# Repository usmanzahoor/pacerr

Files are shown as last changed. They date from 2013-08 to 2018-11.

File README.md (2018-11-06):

#pacerr 

#####Partially Arduino Controled Rover Robot

***PACERR is an arduino based robot that takes commands from a Bluetooth source and translates them into other messages (motor movements).***

#### Short Description

Pacerr can take commands from any Bluetooth terminal as well as the Blackberry 10 app included in the downloads. The app is just a polished version of the simple bluetoothchat example released by Blackberry themselves. I have also included the code for two possible Android apps you can use. They are in the trunk folder of the source. I have not compiled them and you need to do that on your own. 

I have included the necessary bare basic code for the rover. I will also include several different codes you can apply. You can, by all means, use the codes and build upon them or just use them as is to make your own Pacerr. I will also include files such as .pcb and other schematic for the project as I want to make it as easy as possible to have fun with arduino and BT without going through many hassles. All I ask for is a bit of credit :)

#### WIKI

Make **SURE** to read the wiki pages. (Left menu)

#### Site

Checkout the website for some more useful info! 

####Pictures
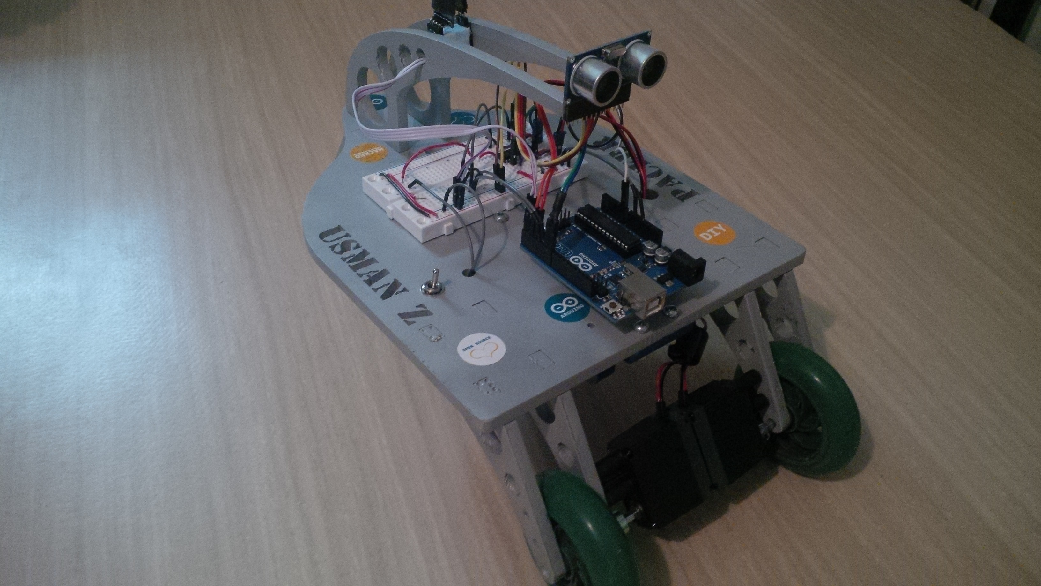
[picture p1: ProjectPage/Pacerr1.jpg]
PACERR Final Picture 2|alt=PACERR being built


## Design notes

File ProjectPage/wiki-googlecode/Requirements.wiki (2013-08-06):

#summary Step 1. Required things for the project.
#labels Requirements,Phase-Requirements

== What do I need? ==

Alright, so let's get started!

What will you need and need to do before the project? Well here is what I did and recommend. 

===Model===
First, you should make some sort of model for your rover. It can be any thing you like and look however you want. I used Autodesk Inventor for my modeling. (If you are a student, get the software for FREE!)  Check out the rendered model I have made. (I will possibly upload my models to GrabCAD, so check that out too)

The only thing to remember when making your models, is to make sure everything goes together nicely and you have plenty of room for the hardware you will need and want to use. 

I will be cutting out my model from aluminum using a waterjet, so when you are making your model, make sure you have someway of cutting it out/ making it. 

===Physical Requirements===
By 'Physical' I mean actual stuff you'll need. 

Here is a basic list:

-An Arduino (I'm using Uno)+ the required software: http://www.arduino.cc/ 

-Fitzrig software for schematics and ordering/making a PCB: http://fritzing.org/

-A Breadboard for prototyping 

-Cables, wires, wire strippers, jumper cables ... 

-Motors (at least 2) (I'm using these ones: http://www.vexrobotics.com/276-2181.html)

-A Bluetooth dongle for arduino 

http://thumbs3.ebaystatic.com/m/mDeCohFDeVs02PIr9CCkcQw/96.jpg

-An Android device or any other with Bluetooth and Bluetooth Terminal capabilities

That's about it for now. And also of course a computer.

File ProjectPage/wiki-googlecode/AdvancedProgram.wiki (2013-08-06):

#summary Step 4.Advanced PACERR program with servo, ultrasonic sensor, photocells and different mode incorporation.
#labels Featured,Phase-Implementation,Phase-Deploy

= Intro =

So now that you've read up on the basic program for the robot (if you haven't make sure you read that before this), you'll be wanting to improve the performance of the robot. 

Because the code is long and complicated, I'll divide it up into various sections for the various parts of the code. 

_Note in Final2.ino, there are some lines of code with `//` in front of them. Theses are currently *NOT* active in the code and you might want to activate them by removing the two slashes. Don't worry if you don't understand what this means yet. After going through these wikis you should have a better idea.

==Review==

This stuff is basically just a review of the basic program. 
So we know that at the top, there are the variable declarations for arduino to know what stands for what and where to store data.

{{{
char incomingByte;
int leftDrivePin = 6;      // left motor
int rightDrivePin = 5;      // right motor
int leftDirectionPin = 7;   // direction - left motor
int rightDirectionPin = 4;  // direction - right motor
}}}

We've already discussed what these lines do in the last page.

{{{
void setup() 
{
  Serial.begin(9600);
  pinMode(leftDrivePin, OUTPUT);
  pinMode(rightDrivePin, OUTPUT);
  pinMode(leftDirectionPin, OUTPUT);
  pinMode(rightDirectionPin, OUTPUT);
  Serial.println("connection successful. enter command, R, B, S, L, or F");
}
}}}

This is the set-up function and it tells arduino if to read signals from a specific pin or send signals or power out. 

{{{
void loop() 
{
  if (Serial.available() > 0) {
    incomingByte = Serial.read();
    if (incomingByte == 'F') {
        digitalWrite(leftDirectionPin,HIGH);
        digitalWrite(leftDrivePin, LOW);
        digitalWrite(rightDirectionPin,HIGH);
        digitalWrite(rightDrivePin, LOW);
        Serial.println("Forwards");
    }
  ...
   }
}
}}}

This is the loop function. This means that the processes in here will continue until power is removed from the arduino.

If you don't understand these parts, you should probably look at the tutorial titled: StepTwoProgramming

==Final2==
===Declarations===

Alright, so now have a look at the sketch Final2.ino. 

There are new lines at the top declaring more things. 

{{{
#include <Servo.h>
}}}

We will be using the servo library that comes with arduino. This line just lets the ide know we will be doing that so we can manipulate the servo easier.

{{{
const int trigPin = 2; // trigPin 
const int echoPin = 3; // echoPin 
}}}

These lines are dependent on the type of ultrasonic sensor you use. I am using the HC-SR04 and on it there are four pins. Vcc (power), Trig, Echo and Gnd.

The trig and echo pins do most of the work. The are connected mainly to the two drums. One of them sends sound signals and the other ones receives (trig and echo). 

Here you declare that the digital pin 2 on the arduino will be connected to the trig pin on the ultrasonic sensor and the same for the echo pin.

{{{
const int lsPin = A1;
const int ambient = 500;    //natural
const int threshold = 600;  //steering 
int lightLeft = 0;
int lightRight = 0; 
}}}

The line `const int lsPin = A1;` is letting the arduino know that Analog pin labeled A! will be used to check if the photocells are active to switch to steering with a flash light mode. 

The lines `const int ambient = 500;` and `const int threshold = 600;` are letting the arduino know that the ambient level of light for the photo cells is 500 and the threshold or the least amount of light needed to steer in 600.

The two `int` statements are just to store the amount of light going to the left and right photocells.

{{{
char incomingByte;          // steering mode commands
const int btPin = A0;
int leftDrivePin = 4;       // left motor
int rightDrivePin = 6;      // right motor
int leftDirectionPin = 5;   // direction - left motor
int rightDirectionPin = 7;  // direction - right motor
int enable1 = 9;            // left motor
int enable2 = 10;           // right motor
}}}

These lines have been discussed in the previous wiki page.

{{{
const int minSafeDist = 35; 
int centerDist, leftDist, rightDist, backDist; // Define variables center, left, right and back distance

Servo myservo; //declare servo
}}}

The `const int minSafeDist = 35;` declares that if there is something 35 cm in front of our robot it should do what we tell it to do (in our case preform a scan for available routes).

The ints are again just ways to store data and the `Servo myservo;` is letting the ide know that from now on we will call our servo `myservo`.

===void setup ()===

{{{
void setup() 
{
  Serial.begin(9600);
  // Set all the pins and the servo
  pinMode(btPin, INPUT);
  pinMode(leftDrivePin, OUTPUT);
  pinMode(rightDrivePin, OUTPUT);
  pinMode(leftDirectionPin, OUTPUT);
  pinMode(rightDirectionPin, OUTPUT);
  //pinMode(lights, OUTPUT);
  pinMode(trigPin, OUTPUT);
  pinMode(echoPin, INPUT);
  digitalWrite(enable1, HIGH);
  digitalWrite(enable2, HIGH);
  myservo.attach(11);
  myservo.write(95);
  // Initial message
  Serial.println("connection successful. enter '?' for list of commands.");
}
}}}

This is pretty self explanatory but if you do not understand it have a look at the previous wiki page (the one you should have already read before this one).

The new lines however I will go over.

{{{
  myservo.attach(11);
  myservo.write(90);
}}}

These lines refer back to our servo called `myservo`. So the .attach command is telling the arduino that we will attach out servo's inout pin to the arduino digital pin 11.

The .write line is telling which angle to set the servo up to start. In this case at 90 degrees so it is looking forwards. And then it can turn 0 degrees to look right and 180 degrees to look left.

===void loop () and the autonomous function===

This is what does the magic for us. 

First, the arduino checks if either the buletooth pin or the photo cells are powered on. If they are, it either goes into manual mode (bluetooth) or lightsteer mode (photocells)/

{{{
//check if we are using the bluetooth module, if so listen for commands only
  if( digitalRead(btPin) == HIGH ) { 
    manual();
    return;
  }
  //check if the photosensors are on, if so follow light only
  if( digitalRead(lsPin) == HIGH && digitalRead(btPin) == LOW ) { 
    lightsteer();
    return;
  }
}}}

That is why above, we connected the bluetooth module to the A0 pin and the photocells to the A1 pin. 

The arduino checks if either of these things is receiving power.
If the bluetooth module is receiving power `if( digitalRead(btPin) == HIGH ) {` and if it is then
 
{{{
    manual();
    return;
}}} 

perform the manual function. Which is basically the void loop of the basic code. 

If the photocells get power AND the bluetooth doesn't get power 'if( digitalRead(lsPin) == HIGH && digitalRead(btPin) == LOW ) {` then:

{{{
    lightsteer();
    return;
}}}

preform the lightsteer function (I'll describe it below).

If none of these things happens, then preform the autonomous functions:

{{{
centerDist = getDistance();  
    
  if(centerDist >= minSafeDist) /* If the inches in front of an object is greater than or equal to the minimum safe distance react*/
  {
    forward(); // All wheels forward for seconds
  }
  else // If not:
  {
    brake(); // Stop all motors
    backward();
    delay(600);
    lookAround(); // Check your surroundings for best route
    if(rightDist > leftDist) // If the right distance is greater than the left distance , turn right
    {
      right();
    }
    else if (leftDist > rightDist) // If the left distance is greater than the right distance , turn left
    {
      left();
    }
    else if ( leftDist&&rightDist < minSafeDist ) // If the left and right distances are smaller than the min safe distance go back
    {
      backward();
      delay(1000);
    }  
  }
}}}

So what's going on here? Well, first of all `centerDist = getDistance();` is saying that to find the distance in front of the robot, you must preform the function called 'getDistance'.

Then, if the center distance is greater than the minimum safe distance, go forward until something comes in front of the robot. 

If there is something in front, then stop (`brake();`) go back a bit (`backward(); delay(600);`) then `lookAround();` for safe distances. 

Once the robot has looked around, this is what happens:

  If the right distance is greater than the left, then turn right for one second and continue forward.

  If the left distance is greater than the right, then turn left for one second and continue forward.  

  If the left and right distances are smaller than the min safe distance go back.

This pretty much covers the 'autonomous' function and how the robot moves around unassisted. Later on, you might want to add a temp and humidity sensor or other data collection sensors and as the robot is moving around, it could send the data back over to serial.

What you'll have to do then, is tell the robot, that when bluetooth is on, still preform auto mode and send serial outs and add a button maybe to switch modes. But right now, you don't have to worry about that.

===Manual method and functions===

The manual methods of this robot are really just the same as the basic program. Have a look and you'll see that the only difference is that there is the line:

{{{
void manual()
{
...
}
}}}

above the code. This is letting the ide (btw, ide stands for integrated development environment, so the program you are using on your computer) know that the lines curly braces are not `void loop ()` like in the basic code but are `void manual ()` and we can call them when ever (well almost when ever) by using `manual();`

An example of this mentioned earlier is in lines 57-60:

{{{
if( digitalRead(btPin) == HIGH ) {
manual();
return;
}
}}}

You'll recognize these from above. So basically what is happening is that we tell the arduino that if btPin, or pin A0, is NOT detecting power, then go ahead and preform the `manual();` function. 

And then we go ahead and let it know what the `manual();` function is exactly by creating a 

{{{
void manual()
{
...
}
}}}

===The light steering function===

{{{
void lightsteer()
{
  // Read light sensors connected to
  // analog pins A2 and A3
    lightLeft = analogRead(A2);
    lightRight = analogRead(A3);
     // Stop robot if below ambient
     if (lightRight < ambient || lightLeft < ambient) {
     brake();
     } else {
     forward();
      // Steer to right if right CdS below threshold
      if (lightRight < threshold) {
      left();
  delay (250);
}
      // Steer to left if left CdS below threshold
      forward();
      if (lightLeft < threshold) {
      right();
  delay (250);
  }
 }
}
}}}

So this function is obviously called by `lightsteer();` (in lines 62 - 65).

Here is what happens: 

The two sensors that we declared near the top of the sketch `lightLeft` and `lightRight` are assigned analog pins `A2` and `A3`.

Now:

  {{{
    if (lightRight < ambient || lightLeft < ambient) {
       brake();
  }}}

  if there is less light than the amount we declared near the top facing both of the photocells, then perform the `brake();` function. or if there is light shining on both both the cells, then perform `forward():`

  and

  {{{
    if (lightRight < threshold) {
        left();
    delay (250);
  }
  }}}

  if there is more light on the right cell, turn left and the opposite for the other cell.

Pretty easy and simple.

===Motor methods===

These functions just are the movement functions, like brake = all motors off and forward = all motors on and left = right motor forward and left motor either off or `LOW`, backwards).

Again, by now you should be able to decipher these as well pretty easily.

===Servo methods===

Something new, yay! But unfortunately (or maybe not for you) pretty easy to understand).

{{{
/* Servo methods */
void lookRight()
{
myservo.write(180);
delay(320);
}

void lookLeft()
{
myservo.write(0);
delay(320);
}

void lookAhead()
{
myservo.write(95);
delay(320);
}

void lookAround()
{
lookRight();
rightDist = getDistance();

lookLeft();
leftDist = getDistance();

lookAhead();
centerDist = getDistance();
}
/* End of servo methods */
}}}

Here we manipulate the `myservo.write( -angle- );` command from the library. So if you look at your servo, 90 degrees is looking forwards and so 180 is looking to the left and 0 is looking to the right.

http://www.seattlerobotics.org/guide/images/pulse_code.jpg

In every function, we use the .write command to move the servo at a specific angle then in the `void lookAround()` we store the measurement data.

So in `void lookAround()` we `lookRight();` then we `getDistance();` and then we store it in the variable we declared at the top of the code as `rightDist` and so on for the other angles.

===The ultrasonic sensor explained===

{{{
int getDistance()
{
long duration;
digitalWrite(trigPin, LOW);
delayMicroseconds(2);
digitalWrite(trigPin, HIGH);
delayMicroseconds(10);
digitalWrite(trigPin, LOW);
duration = pulseIn(echoPin, HIGH);
return duration / 2 / (29+(1/10));
}
}}}

The ultrasonic sensor, in most cases has two 'drums' and sometimes even just one that does both jobs. I'll explain the HC-SR04.

On the U' sensor, one 'drum' is trig and the other is 'echo'. Look at the following diagram:

http://www.robotc.net/w/images/thumb/c/c8/Ultrasonic_Sensor_Concept_Diagram.png/400px-Ultrasonic_Sensor_Concept_Diagram.png

In the code block, we first do `long duration;` this is just saying we are making a new variable called 'duration' to store data.

What we do in the next few lines is make trigPin send out ultrasonic waves and as the bounce back, make the pulse pin determine how long it took in ms.

Then we say ok, the 'duration' is the time it took. 

Now comes the bit that turns the duration into the distance.

{{{
return duration / 2 / (29+(1/10));
}}}

What we do is take the 'duration' and divide it by 2 then by 29.1 and this gives us the distance to the object which the u' sensor is facing. 

==Final notes==

So hopefully now you understand the code that makes the robot do what it does. Feel free to change the code to your liking and use it but make sure you follow the license terms.

If you have any questions about the code, feel free to email me at:
_*uzahoor10@gmail.com*_

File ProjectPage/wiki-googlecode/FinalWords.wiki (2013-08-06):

#summary Done!Final notes and info for hook up.
#labels Phase-Support

I hope you enjoyed and learned lots from the wiki pages.

Hopefully now you understand the code that makes the robot do what it does. 

Feel free to change the code to your liking and use it but make sure you follow the license terms.

If you have any questions about the code, feel free to email me at:
_*uzahoor10@gmail.com*_

I will post pictures of my own robot. All the code I used is available (for the arduino as well as the android and blackberry apps).

I will also post pictures of the hook-up so you get a good idea of how to set the robot up. 

You will find this hook-up diagram in the downloads tab.

==Hook-up==

For the hook-up, the IC (chip connected to the motor pins), is what controls the motors.

As I mentioned before, *DO NOT* simple attach the motors to the arduino you *MUST* use an h-bridge:

http://fritzing.org/media/fritzing-repo/projects/a/arduino-l293d/images/l293d_pl.jpg

http://3.bp.blogspot.com/-ou_idTKaKFU/UQkOzgdzbnI/AAAAAAAAArM/_jYpJ7KwSfQ/s1600/WORKING.jpg

==L293D==

Follow the above diagram *BUT* for pins 1 & 9 attach them to the arduino pins 9 & 10.

This is so you can control the motor speeds if you want later on.

Thanks for reading! :D

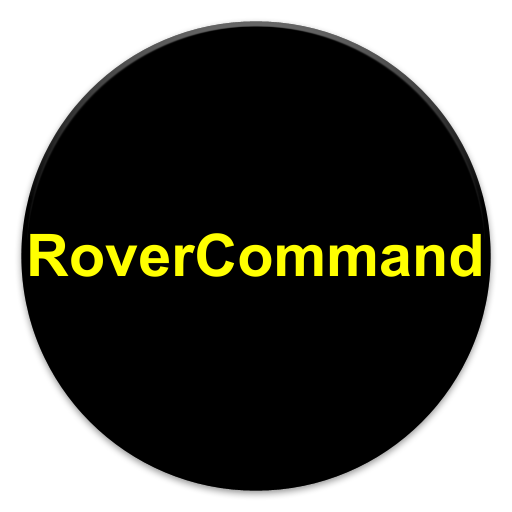
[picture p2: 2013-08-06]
Android/RoverCommandv2/ic_launcher-web.png

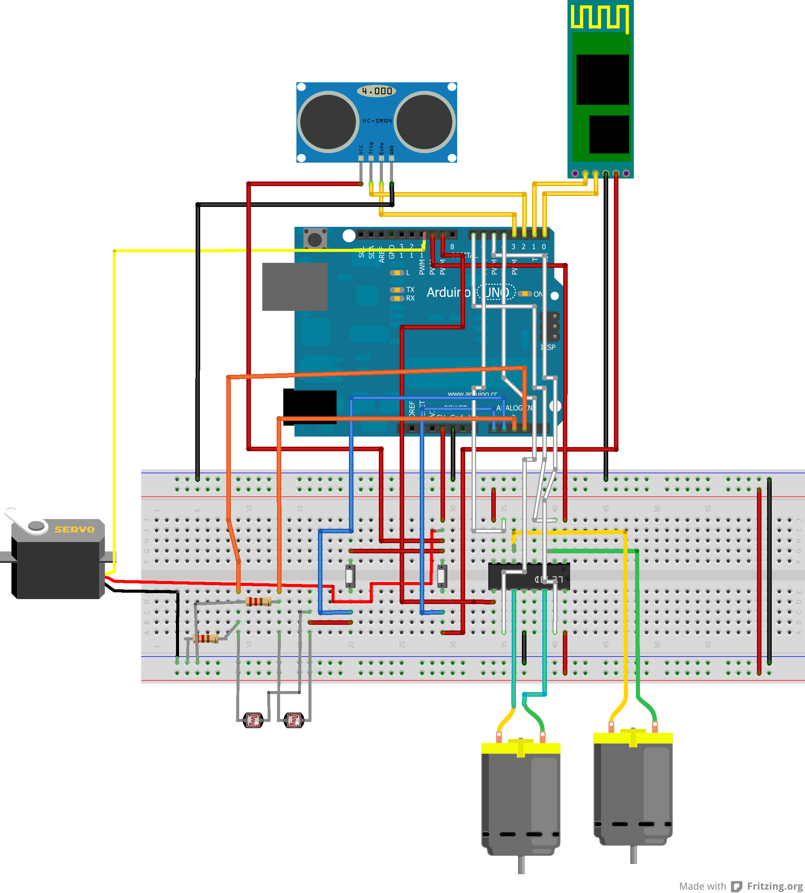
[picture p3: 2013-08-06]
HookUp/Hook-up.png

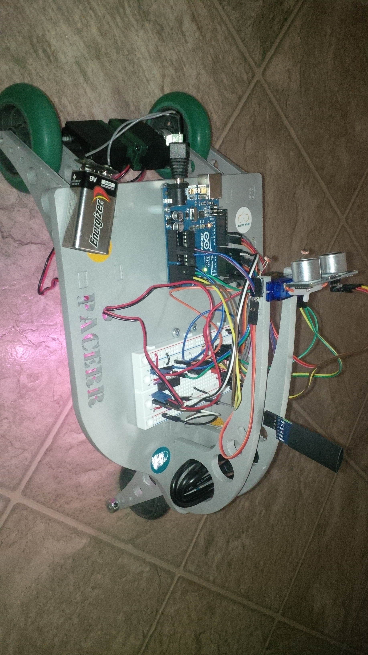
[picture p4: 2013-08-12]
ProjectPage/Pacerr2.jpg

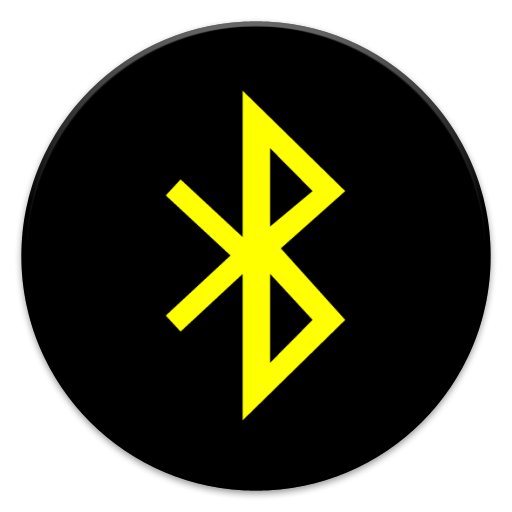
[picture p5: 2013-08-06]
Android/RoverCommand/ic_launcher-web.png

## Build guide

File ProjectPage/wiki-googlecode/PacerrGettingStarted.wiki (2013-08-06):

#summary Intro to project. MUST READ!
#labels Featured,Phase-Requirements

= Introduction =

Hello,
Welcome to PACERR! As mentioned before, this project is a part of a school project called ENEX. 

To learn a bit about the project, look at the project homepage: http://code.google.com/p/pacerr. 

So first of all, let me tell you that this ‘robot’ will work with two motors or four motors. With four motors, you would just run the command pins at the same place as the other motor on the adjacent side.

O,,1,,    O,,2,,

O,,1,,   O,,2,,

As you can see above, the command pins for both O1 motors will be the same or on a breadboard on the same pin side and the ones for O2 will be the same.

For this project, I will only be providing code assuming that you are only using two motors or the situation mentioned above. 

Also, the specific Android app will also need to be tweaked for your custom needs. For example, you will need to use the code for the .apk and modify the MAC address lines in the ‘src/com/example/rovercommand/mainactivity’ and add the MAC address of your OWN Bluetooth module. 

I have also made a blackberry 10 app: http://appworld.blackberry.com/webstore/content/26018872/?countrycode=CA

As you can tell the android app code compliments the arduino code. For example, in the arduino code, I have defined the command for ‘forwards’ as simple ‘F’. This means that only the Bluetooth command ‘F’ will make the motors turn in a forward direction. Now in the app’s java file (mentioned above), you will see that the button ‘Forwards’ sends the command ‘F’ which results in a forward motion. If you want to change the arduino code, you will have to also modify the app. For my final presentation, I will greatly modify the GUI of the app and also add a text reader so the user can modify the MAC address without having to recompile the app.

For the blackberry app, you have the option to search for the bluetooth device and the deploy commands via terminal (SPP).

You can use a simple Bluetooth terminal and send the commands: F, B, S, L, or R and the motors should respond. But you will need to connect the Bluetooth module to the specific Bluetooth terminal you will be using. 

So, let's get started. Check out the next wiki page!

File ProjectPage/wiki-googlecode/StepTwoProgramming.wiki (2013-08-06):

#summary Step 3. Now on to the programming.
#labels Featured,Phase-Implementation

=Programming with the simple code=

Alright, so now you have your model or sketch ready. Now what?

Well, let's get on to the programming aspect. I have provided, in the downloads and source tabs, different ways to program arduino.

The ENEXRoverX.ino sketches (btw arduino code files are called sketches) are just simple ways to control the robot with serial (or bluetooth).

First, let me explain how everything works.

===ENEXRoverX.ino code files and how they work + Arduino functionality===

The first lines of code above the void loop () function are to let arduino know which pins do what. 

{{{
char incomingByte;
int leftDrivePin = 6;      // left motor
int rightDrivePin = 5;      // right motor
int leftDirectionPin = 7;   // direction - left motor
int rightDirectionPin = 4;  // direction - right motor
}}}

The 'char incomingByte line is declaring the fact that in the loop function where we look for the serial commands, the commands (ie "F" or "B") will be stored in a variable called "incomingByte".

(the "//" lines are just comments )

Now we come to the "int"s. As you can see, there are two variables for each motor; DrivePin and DirectionPin. These can be called whatever you want. What they do is assign the two pins of the motor. 

For example, if you were to put the motor directly into Arduino (this is just for explaining *DO NOT* actually do this as it can damage your arduino) one of the wires would go into one of the pins and the other into the other pin.

Here we have leftDrivePin set to 6 and leftDirectionPin set to 7. This means that for the left motor, you would put one of the wires, either negative (black usually) or positive into either pin. Same goes for the other motor. 

{{{
void setup() 
{
  Serial.begin(9600);
  pinMode(leftDrivePin, OUTPUT);
  pinMode(rightDrivePin, OUTPUT);
  pinMode(leftDirectionPin, OUTPUT);
  pinMode(rightDirectionPin, OUTPUT);
  Serial.println("connection successful. enter command, R, B, S, L, or F");
}
}}}

This is the set-up function and it tells arduino if to read signals from a specific pin or send signals or power out. 

The first line `Serial.begin(9600);` is to tell arduino that we will be working with the serial monitor and sending it signals from there. 

The lines after that tell the arduino that the pins we declared above (the motor pins) will be used as outputs (we will be _sending_ power or signals to them not _receiving_).

The last line `Serial.println("connection ... F");` is telling the arduino to print the message in the quotes to the serial monitor we started above using `Serial.begin(9600);`.

  ====How serial works and how Bluetooth is used====

  The serial monitor is located in the top right corner of the arduino   ide. It looks like a magnifying glass and if you hover over it, you will see that is says serial monitor. 

  When you use the command `Serial.printIn(" ")` the arduino prints the message in the quotes into the monitor when you declare it to be printed. 

  You will see exactly what I mean later on in this wiki. 

  The serial can be replaced with anything that is attached to the TX and RX pins on the arduino. (located in the same row as the digital pins) This stands for receive and transmit respectively. 

  Now if you want to view the messages or send signals, you must connect these pins to some sort of capable input (ie bluetooth module). 

  The pins on the Bluetooth module labeled RX and TX attach here. 

  =====The RX pin goes with the TX pin and the TX pins goes with the RX pin!=====

  Once you have the power pin and ground pins connected, you can connect the Bluetooth module to a terminal and view commands sent and send your own commands. 

{{{
void loop() 
{
  if (Serial.available() > 0) {
    incomingByte = Serial.read();
    if (incomingByte == 'F') {
        digitalWrite(leftDirectionPin,HIGH);
        digitalWrite(leftDrivePin, LOW);
        digitalWrite(rightDirectionPin,HIGH);
        digitalWrite(rightDrivePin, LOW);
        Serial.println("Forwards");
    }
  ...
   }
}
}}}

This is the loop function. This means that the processes in here will continue until power is removed from the arduino.

The line `if (Serial.available() > 0) {` ells the arduino to look for serial commands and if the commands are available (or greater than 0) the do the following. 

Then the arduino is told `incomingByte = Serial.read();`. This tells it that the commands given to the arduino will be stored in the variable called incomingByte. `Serial.read();` is what reads the commands. 

After this, comes `if (incomingByte == 'F') {`; this is saying that if the "incomingByte" or the command is 'F' do the following:

{{{
        digitalWrite(leftDirectionPin,HIGH);
        digitalWrite(leftDrivePin, LOW);
        digitalWrite(rightDirectionPin,HIGH);
        digitalWrite(rightDrivePin, LOW);
        Serial.println("Forwards");
}}}

`digitalWrite(leftDirectionPin, HIGH);` :

Make the leftDirPin HIGH, or supply it with power. And make the other pins HIGH or LOW respectively. 

`Serial.println("Forwards");` :

This tells the arduino that when the robot starts to move forward, display the message "Forwards".

If you look at the other commands, you will be able to depict what they mean by looking at this problem. 

  In Final.ino you will see two new commands initiated by "U" and "T". These are used for the ultrasonic sensor and the lm35 temperature. 
  I will not heavily explain these as tutorials for them are easy to find online. However, I will tell you how to implement them into the code.
  First you must find working code for these sensors and then you literally merge the variables and setups. 
  
  For example, take the code above the void setup () functions and add it to the code with the commands do the same with the setup () lines and the loop you will add to `if (incomingByte == 'F') { _loop here_ }`.

Now look at the next tutorial titled: Advanced Program for the 'Final2' program for the advanced code with servos and us sensor robot.

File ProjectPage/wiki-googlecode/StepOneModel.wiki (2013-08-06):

#summary Step 2. Technical step one. Get your model ready
#labels Model,Phase-Design,Featured

==Model==

Alright, so now you have everything ready. Time to start deciding on how your rover will look like. Look at the model I have uploaded to 'downloads' to get an idea of what it might look like. 

Your robot can look however you want, just make sure there is enough room for everything. 

So how would you start modeling? We'll I used this software:
Open: http://usa.autodesk.com/autodesk-inventor/
Go to: Trial version or buy the full version

IF you are a student, then:
Open: http://students.autodesk.com/?nd=download_center
Scroll to: Autodesk Inventor Professional
And follow: 'Download' instructions

You do not have to necessarily use this expensive, software, I am sure you would do just as well with something like Google Sketchup Basic. But make sure that if you are going to use a waterjet or similar machine, you use proper drafting software. 

As a matter of fact, if you are just going to be building the chassis yourself, you could even get away with simply sketching the design. 

But with the designing software, you can make sure everything fits and you have enough room.

Here are the models for my final rover design (note: version 2 was the version built):

http://grabcad.com/library/pacerr-robot-v2
http://grabcad.com/library/pacerr-rover-v1

As you seen, my models are pretty complicated and detailed. You just have to make sure you have some sort of design laid out for the body of your robot.

Some things to keep in mind are:

- The robot must have room for the arduino, a breadboard (if necessary), and extra sensors that you wish to add.
- The robot must be made of a good material (I used aluminum but you could use anything like plastic, other good metal or even wood)

These are just some guidelines and when you have finished making you physical robot, head on to the next tutorial for the next step.

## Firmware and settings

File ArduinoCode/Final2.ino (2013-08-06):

/* PACERR - Partially Arduino Controlled ENEX Rover Robot
Easy robot build that is reprogamable to suit your needs.

Copyright (C) 2013 Usman Zahoor

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
code.google.com/p/pacerr for more info
*/

//include libraries
#include <Servo.h>

//set up ultrasonic sensor
const int trigPin = 2; // trigPin
const int echoPin = 3; // echoPin

const int horn = 12; // horn

//set up lightsteer
const int lsPin = A1;
const int ambient = 400; //natural light level
const int threshold = 460; //steering light level
int lightLeft = 0;
int lightRight = 0;

//set up manual steer
char incomingByte; // steering mode commands
const int btPin = A0;
int leftDrivePin = 4; // left motor
int rightDrivePin = 6; // right motor
int leftDirectionPin = 5; // direction - left motor
int rightDirectionPin = 7; // direction - right motor
int enable1 = 9; // left motor
int enable2 = 10; // right motor

const int minSafeDist = 30;
int centerDist, leftDist, rightDist, backDist; // Define variables center, left, right and back distance


Servo myservo; //declare servo

void setup()
{
Serial.begin(9600);
// Set all the pins and the servo
pinMode(btPin, INPUT);
pinMode(leftDrivePin, OUTPUT);
pinMode(rightDrivePin, OUTPUT);
pinMode(leftDirectionPin, OUTPUT);
pinMode(rightDirectionPin, OUTPUT);
pinMode(horn, OUTPUT);
pinMode(trigPin, OUTPUT);
pinMode(echoPin, INPUT);
digitalWrite(enable1, HIGH);
digitalWrite(enable2, HIGH);
myservo.attach(11);
myservo.write(95);
// Initial message
Serial.println("connection successful. enter '?' for list of commands.");
}

void loop()
{
//check if we are using the bluetooth module, if so listen for commands only
if( digitalRead(btPin) == HIGH ) {
manual();
return;
}
//check if the photosensors are on, if so follow light only
if( digitalRead(lsPin) == HIGH && digitalRead(btPin) == LOW ) {
lightsteer();
return;
}

centerDist = getDistance();

if(centerDist >= minSafeDist) /* If the inches in front of an object is greater than or equal to the minimum safe distance react*/
{
forward(); // All wheels forward for seconds
}
else // If not:
{
brake(); // Stop all motors
beep();
backward();
lookAround(); // Check your surroundings for best route
if(rightDist > leftDist) // If the right distance is greater than the left distance , turn right
{
right();
}
else if (leftDist > rightDist) // If the left distance is greater than the right distance , turn left
{
left();
}
else if ( leftDist&&rightDist < minSafeDist ) // If the left and right distance is smaller than the min safe distance go back
{
backward();
delay(1000);
}
}
}

/*-------------------------------------------------------------------------------------------------------------------------------------------------------------------------------------------------------------------------------------------------------------------------------------------------------------------*/

/*manual methods*/
void manual()
{
if (Serial.available() > 0) {
incomingByte = Serial.read();

if (incomingByte == '?'){ // Help command responce
Serial.println("welcome to the help menue. here is a list of commands for steering: f - forwards, b - backwards, r - rotate right, l - rotate left, s - stop, h - buzzer.. visit project page for more info: code.google.com/p/pacerr - by usman zahoor");
}
if (incomingByte == 'f'|| incomingByte == 'F' ) { // Forwards command
digitalWrite(leftDirectionPin,HIGH);
digitalWrite(leftDrivePin, LOW);
digitalWrite(rightDirectionPin,HIGH);
digitalWrite(rightDrivePin, LOW);
Serial.println("Forwards");
}
if (incomingByte == 'b'|| incomingByte == 'B' ) { //Backwards command
digitalWrite(leftDirectionPin,LOW);
digitalWrite(leftDrivePin, HIGH);
digitalWrite(rightDirectionPin,LOW);
digitalWrite(rightDrivePin, HIGH);
Serial.println("Reverse");
}
if (incomingByte == 's'|| incomingByte == 'S' ) { // Brake command
digitalWrite(leftDirectionPin,LOW);
digitalWrite(leftDrivePin, LOW);
digitalWrite(rightDirectionPin,LOW);
digitalWrite(rightDrivePin, LOW);
Serial.println("Brake");
}
if (incomingByte == 'l'|| incomingByte == 'l' ) { //Left command
digitalWrite(leftDirectionPin,LOW);
digitalWrite(leftDrivePin, HIGH);
digitalWrite(rightDirectionPin,HIGH);
digitalWrite(rightDrivePin, LOW);
delay(1000);
Serial.println("Turning Left");
}
if (incomingByte == 'r'|| incomingByte == 'R' ) { // Rightcommand
digitalWrite(leftDirectionPin,HIGH);
digitalWrite(leftDrivePin, LOW);
digitalWrite(rightDirectionPin,LOW);
digitalWrite(rightDrivePin, HIGH);
delay(1000);
Serial.println("Turning Right");
}
if (incomingByte == 'h'|| incomingByte == 'H' ) { // horn command
beep();
}
}
}

/*light steering methods*/
void lightsteer()
{
// Read light sensors connected to
// analog pins A0 and A1
lightLeft = analogRead(A2);
lightRight = analogRead(A3);
// Stop robot if below ambient
if (lightRight < ambient || lightLeft < ambient) {
brake();
} else {
forward();
// Steer to right if right CdS below threshold
if (lightRight < threshold) {
left();
delay (250);
}
// Steer to left if left CdS below threshold
forward();
if (lightLeft < threshold) {
right();
delay (250);
}
}
}
/* End of light steering methods */

/* Motor methods */
void brake()
{
digitalWrite(leftDirectionPin,LOW);
digitalWrite(leftDrivePin, LOW);
digitalWrite(rightDirectionPin,LOW);
digitalWrite(rightDrivePin, LOW);
Serial.println("Brake");
}

void forward()
{
digitalWrite(leftDirectionPin,HIGH);
digitalWrite(leftDrivePin, LOW);
digitalWrite(rightDirectionPin,HIGH);
digitalWrite(rightDrivePin, LOW);
Serial.println("Forwards");
//delay();

}

void backward()
{
digitalWrite(leftDirectionPin,LOW);
digitalWrite(leftDrivePin, HIGH);
digitalWrite(rightDirectionPin,LOW);
digitalWrite(rightDrivePin, HIGH);
Serial.println("Reverse");
delay(200);

}

void left()
{
digitalWrite(leftDirectionPin,LOW);
digitalWrite(leftDrivePin, HIGH);
digitalWrite(rightDirectionPin,HIGH);
digitalWrite(rightDrivePin, LOW);
delay(800);
Serial.println("Turning Left");
}

void right()
{
digitalWrite(leftDirectionPin,HIGH);
digitalWrite(leftDrivePin, LOW);
digitalWrite(rightDirectionPin,LOW);
digitalWrite(rightDrivePin, HIGH);
delay(800);
Serial.println("Turning Right");
}
/* End of Motor methods */

/* Servo methods */
void lookRight()
{
myservo.write(180);
delay(320);
}

void lookLeft()
{
myservo.write(0);
delay(320);
}

void lookAhead()
{
myservo.write(95);
delay(320);
}

void lookAround()
{
lookRight();
rightDist = getDistance();

lookLeft();
leftDist = getDistance();

lookAhead();
centerDist = getDistance();
}
/* End of servo methods */

/* Sensor methods */
int getDistance()
{
long duration;
digitalWrite(trigPin, LOW);
delayMicroseconds(2);
digitalWrite(trigPin, HIGH);
delayMicroseconds(10);
digitalWrite(trigPin, LOW);
duration = pulseIn(echoPin, HIGH);
return duration / 2 / (29+(1/10));
}
/* End of sensor methods */

void beep (){
  digitalWrite(horn,HIGH);
  delay(200);
  digitalWrite(horn,LOW); 
}

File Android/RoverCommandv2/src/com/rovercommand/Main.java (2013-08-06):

package com.rovercommand;

import java.io.IOException;
import java.io.OutputStream;
import java.util.UUID;
import android.app.Activity;
import android.bluetooth.BluetoothAdapter;
import android.bluetooth.BluetoothDevice;
import android.bluetooth.BluetoothSocket;
import android.content.Intent;
import android.content.SharedPreferences;
import android.os.Bundle;
import android.util.Log;
import android.view.View;
import android.view.View.OnClickListener;
import android.widget.Button;
import android.widget.Toast;

public class Main extends Activity {
  private static final String TAG = "RoverCommand";
   
  Button r, b, f, l, s;
   
  private static final int REQUEST_ENABLE_BT = 1;
  private BluetoothAdapter btAdapter = null;
  private BluetoothSocket btSocket = null;
  private OutputStream outStream = null;
  
   
  // Well known SPP UUID
  private static final UUID MY_UUID =
      UUID.fromString("00001101-0000-1000-8000-00805F9B34FB");
 
  // Insert your server's MAC address
  private static String address = "00:12:11:24:92:01";
   
  /** Called when the activity is first created. */
  @Override
  public void onCreate(Bundle savedInstanceState) {
    super.onCreate(savedInstanceState);
    Log.d(TAG, "In onCreate()");
    setContentView(R.layout.main);
    
    SharedPreferences sharedPreferences = getSharedPreferences("PREFS", MODE_PRIVATE);
    final String fwd = sharedPreferences.getString("fwd", "");
    final String bwd = sharedPreferences.getString("bwd", "");
    final String rgt = sharedPreferences.getString("rgt", "");
    final String lft = sharedPreferences.getString("lft", "");
    final String stp = sharedPreferences.getString("stp", "");
    String mac = sharedPreferences.getString("mac", "");

    
    r = (Button) findViewById(R.id.r);
    b = (Button) findViewById(R.id.b);
    l = (Button) findViewById(R.id.l);
    f = (Button) findViewById(R.id.f);
    s = (Button) findViewById(R.id.s);
    
    btAdapter = BluetoothAdapter.getDefaultAdapter();
    checkBTState();
 
    f.setOnClickListener(new OnClickListener() {
      public void onClick(View v) {
        sendData(fwd);
        Toast msg = Toast.makeText(getBaseContext(),
            "Going Forwards", Toast.LENGTH_SHORT);
        msg.show();
      }
    });
    
    l.setOnClickListener(new OnClickListener() {
        public void onClick(View v) {
          sendData(lft);
          Toast msg = Toast.makeText(getBaseContext(),
              "Going Left", Toast.LENGTH_SHORT);
          msg.show();
        }
      });
    
    r.setOnClickListener(new OnClickListener() {
        public void onClick(View v) {
          sendData(rgt);
          Toast msg = Toast.makeText(getBaseContext(),
              "Going Back", Toast.LENGTH_SHORT);
          msg.show();
        }
      });
    
    s.setOnClickListener(new OnClickListener() {
        public void onClick(View v) {
          sendData(stp);
          Toast msg = Toast.makeText(getBaseContext(),
              "Brake", Toast.LENGTH_SHORT);
          msg.show();
        }
      });
    
    b.setOnClickListener(new OnClickListener() {
      public void onClick(View v) {
        sendData(bwd);
        Toast msg = Toast.makeText(getBaseContext(),
            "Going Backwards", Toast.LENGTH_SHORT);
        msg.show();
      }
    });
    
    Button b = (Button) findViewById(R.id.config);
    b.setOnClickListener(new View.OnClickListener() {
       public void onClick(View arg0) {
       Intent i = new Intent(Main.this, Config.class);
       startActivity(i);
       }
    });
  }
   
  @Override
  public void onResume() {
    super.onResume();
 
    Log.d(TAG, "...In onResume - Attempting client connect...");
   
    // Set up a pointer to the remote node using it's address.
    BluetoothDevice device = btAdapter.getRemoteDevice(address);
   
    // Two things are needed to make a connection:
    //   A MAC address, which we got above.
    //   A Service ID or UUID.  In this case we are using the
    //     UUID for SPP.
    try {
      btSocket = device.createRfcommSocketToServiceRecord(MY_UUID);
    } catch (IOException e) {
      errorExit("Bluetooth Connection Error", "In onResume() and socket create failed: " + e.getMessage() + ".");
    }
   
    // Discovery is resource intensive.  Make sure it isn't going on
    // when you attempt to connect and pass your message.
    btAdapter.cancelDiscovery();
   
    // Establish the connection.  This will be blocked until it connects.
    Log.d(TAG, "...Connecting...");
    try {
      btSocket.connect();
      Log.d(TAG, "...Connection established and data link opened...");
    } catch (IOException e) {
      try {
        btSocket.close();
      } catch (IOException e2) {
        errorExit("Bluetooth Connection Error", "In onResume() and unable to close socket during connection failure" + e2.getMessage() + ".");
      }
    }
     
    // Create a data stream so we can talk to server.
    Log.d(TAG, "...Creating Socket to send signals...");
 
    try {
      outStream = btSocket.getOutputStream();
    } catch (IOException e) {
      errorExit("Connection Error", "In onResume() and output stream creation failed:" + e.getMessage() + ".");
    }
  }
 
  @Override
  public void onPause() {
    super.onPause();
 
    Log.d(TAG, "...In onPause()...");
 
    if (outStream != null) {
      try {
        outStream.flush();
      } catch (IOException e) {
        errorExit("Connection Error", "In onPause() and failed to flush output stream: " + e.getMessage() + ".");
      }
    }
 
    try     {
      btSocket.close();
    } catch (IOException e2) {
      errorExit("Connection Error", "In onPause() and failed to close socket." + e2.getMessage() + ".");
    }
  }
   
  private void checkBTState() {
    // Check for Bluetooth support and then check to make sure it is turned on
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

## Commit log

2013-08-06 Added svn project from google code
    [Hook-up.fzz]
2013-08-11 New project layout
    [Hook-up.fzz]

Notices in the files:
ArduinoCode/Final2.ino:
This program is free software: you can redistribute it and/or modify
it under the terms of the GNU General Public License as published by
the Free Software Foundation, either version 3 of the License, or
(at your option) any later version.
